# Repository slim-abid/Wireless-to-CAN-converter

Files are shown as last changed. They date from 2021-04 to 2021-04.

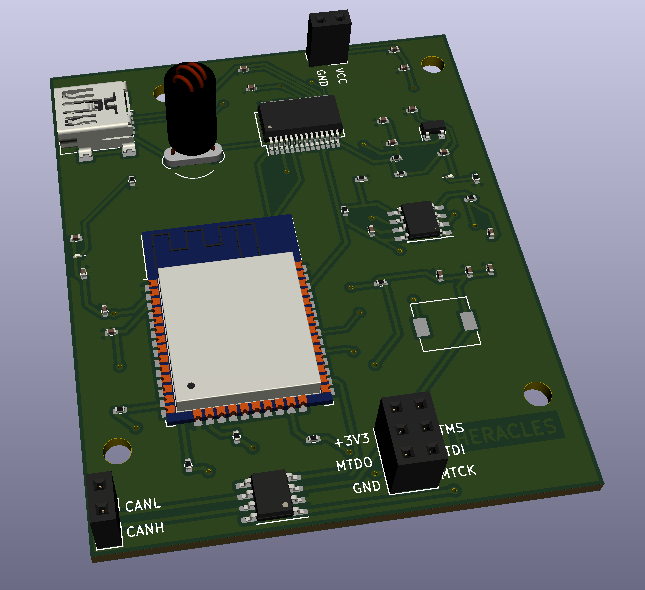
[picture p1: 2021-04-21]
Assets/heracles 3D view.png

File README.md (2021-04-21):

# **Wireless to CAN converter**

Heracles is a qualified board for Automotive Applications.
The board was designed by KiCad.
It introduces the convertion between wireless connection (Bluetooth,BLE,WIFI) and CAN with the following features:

 - [ ] introduces a jtag debugging interface.
 
 - [ ] can be configured and managed by the integrated USB interface.
 
 - [ ] uses 3.8 to 38 V dc alimentation with very low drop down voltage
       values and very low power consumption .
 - [ ] ESP32­WROOM­32 running at 40Mhz to 160MHz.
 
 - [ ] A USB to UART converter.
 
 - [ ] USB type B port.
 
 - [ ] low-power co-processor that can be used instead of the CPU to
       save power while performing tasks that do not require much
       computing power, such as monitoring of peripherals.
       
 - [ ] Wireless connectivity: WI-FI (802.11 b/g/n ,802.11n up to 150
       Mbps), Bluetooth v4.2 and BLE.

## Schematic:



## PCB Routing
heracles2
*All this capabilities are just in 6.65cmx5.35cm board.*

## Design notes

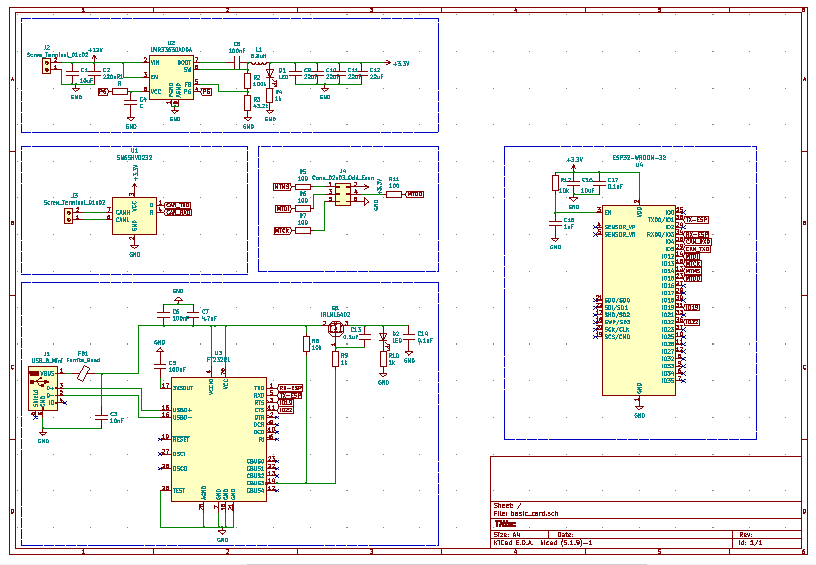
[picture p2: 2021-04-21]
Assets/HeraclesSchema.png

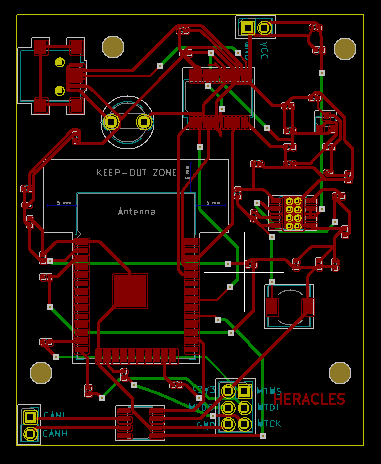
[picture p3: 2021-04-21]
Assets/heracles PCB routing.png

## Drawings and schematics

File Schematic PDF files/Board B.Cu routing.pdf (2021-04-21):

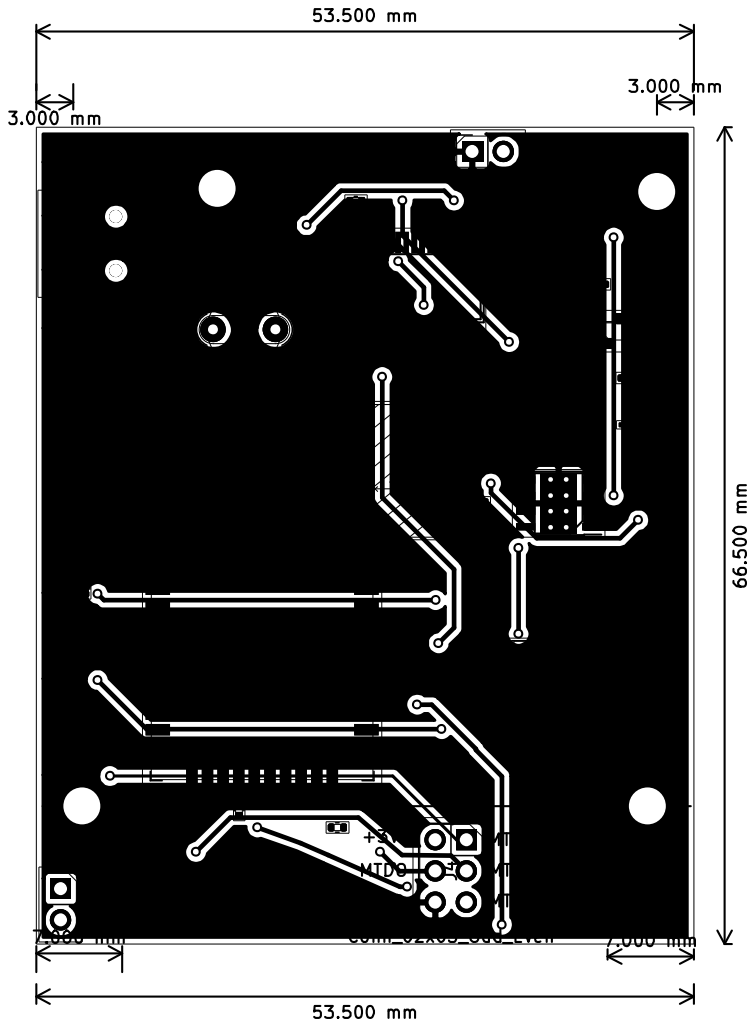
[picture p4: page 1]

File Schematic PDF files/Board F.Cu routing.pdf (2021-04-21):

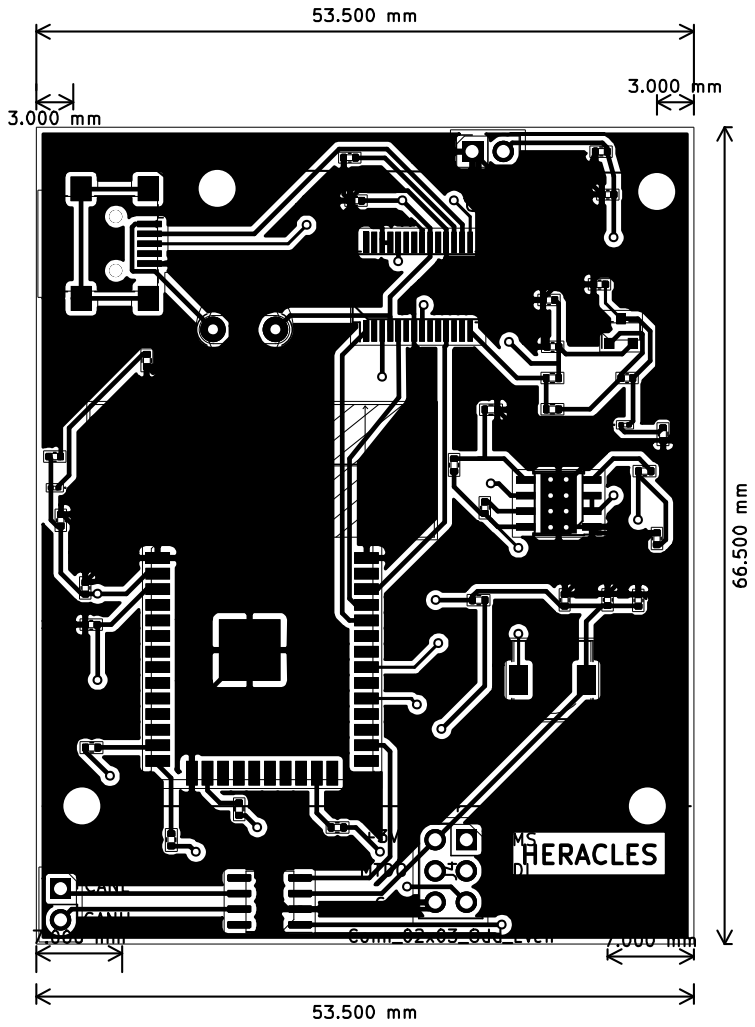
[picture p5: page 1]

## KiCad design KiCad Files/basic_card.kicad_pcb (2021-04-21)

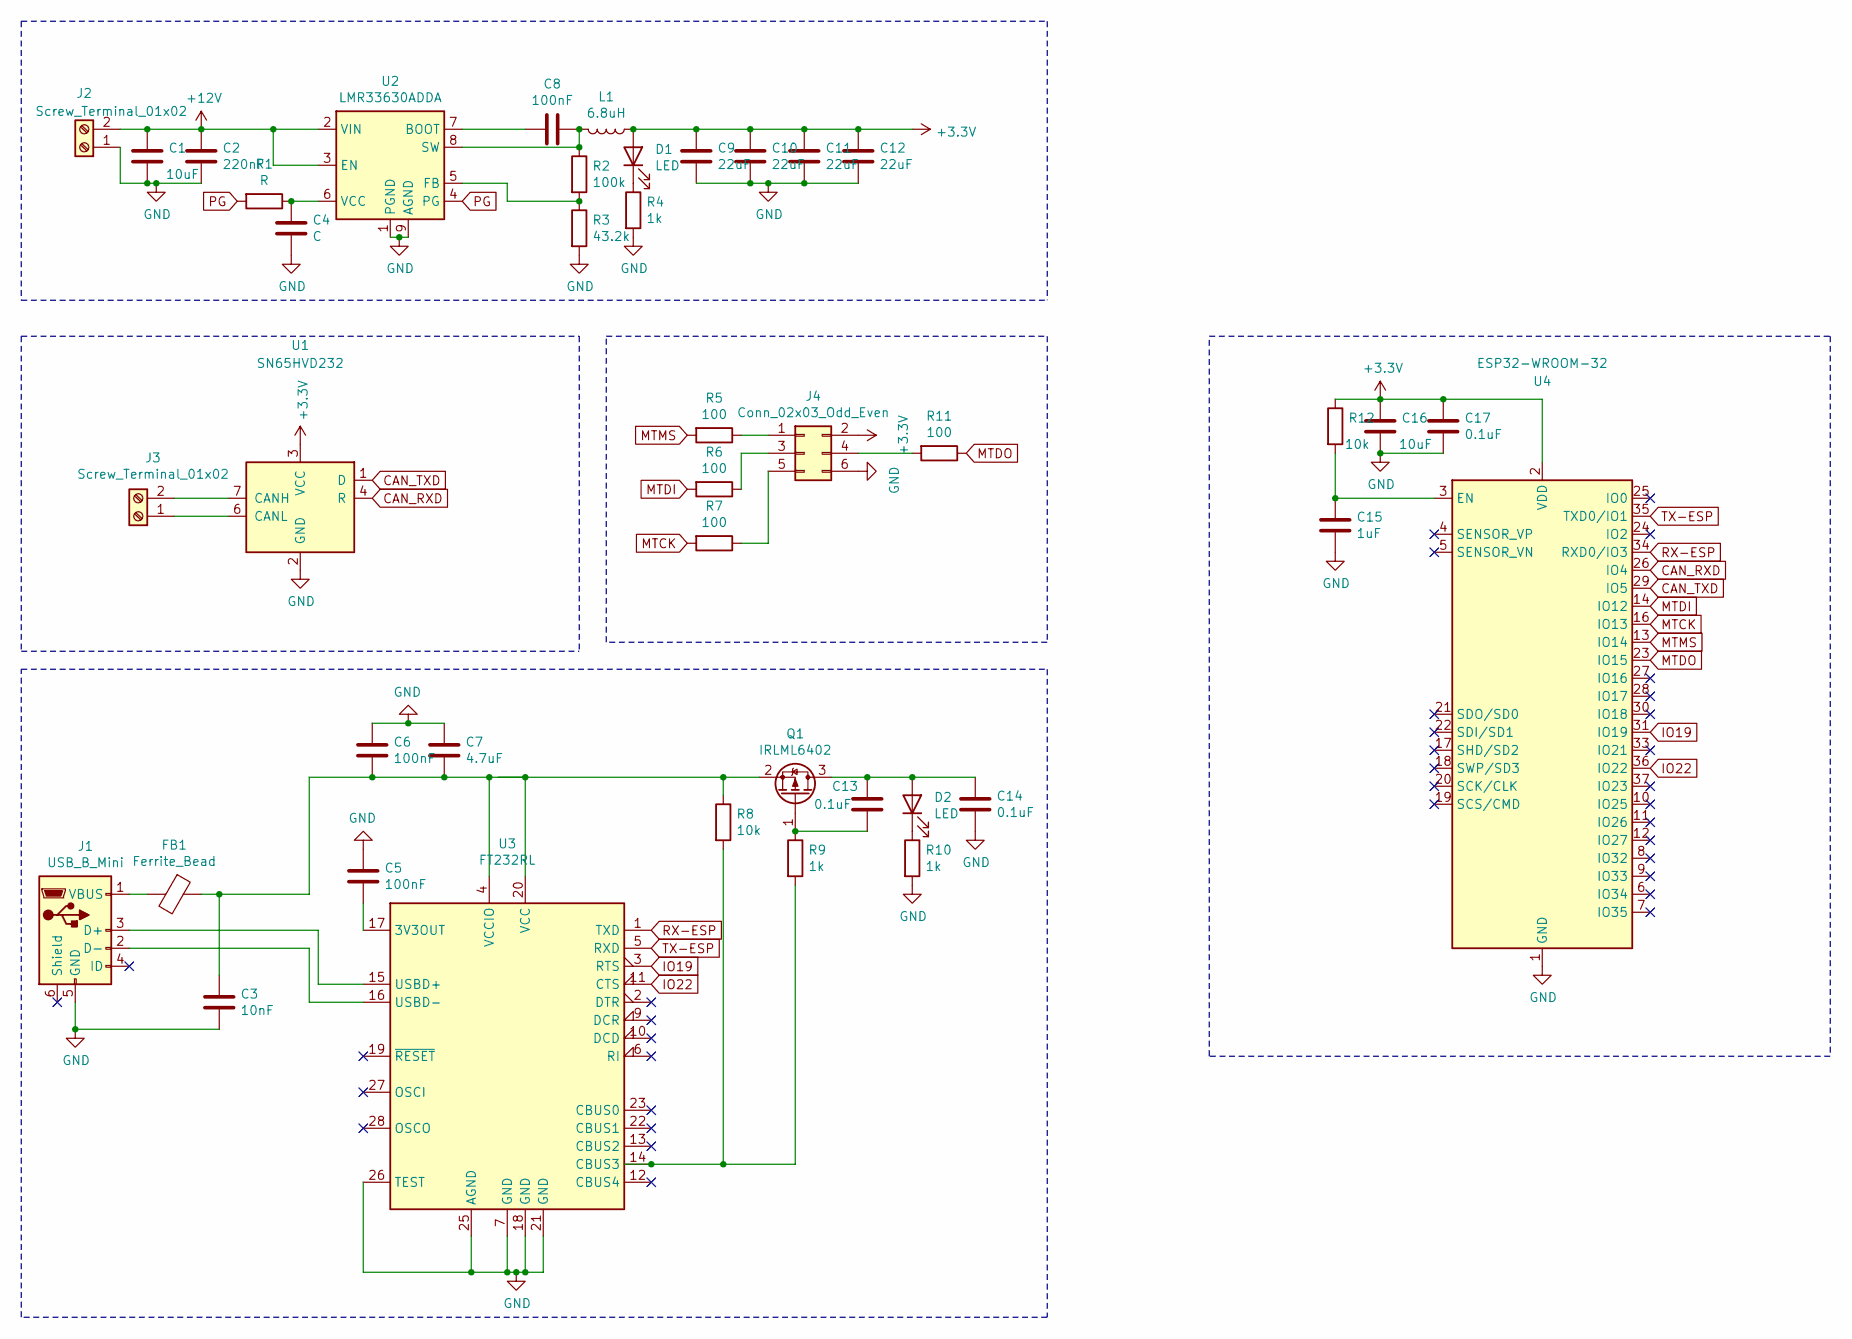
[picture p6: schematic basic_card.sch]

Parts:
C1, C16: 10uF; C_0402_1005Metric
C2: 220nF; C_0402_1005Metric
C3: 10nF; C_0402_1005Metric
C4: C; C_0402_1005Metric
C5, C6, C8: 100nF; C_0402_1005Metric
C7: 4.7uF; C_0402_1005Metric
C9, C10, C11, C12: 22uF; C_0402_1005Metric
C13, C14, C17: 0.1uF; C_0402_1005Metric
C15: 1uF; C_0402_1005Metric
D1, D2: LED; LED_0201_0603Metric
FB1: Ferrite_Bead; LairdTech_28C0236-0JW-10
J1: USB_B_Mini; USB_Mini-B_Lumberg_2486_01_Horizontal
J2, J3: Screw_Terminal_01x02; PinSocket_1x02_P2.54mm_Vertical
J4: Conn_02x03_Odd_Even; PinSocket_2x03_P2.54mm_Vertical
L1: 6.8uH; L_6.3x6.3_H3
Q1: IRLML6402; SOT-23
R1: R; R_0402_1005Metric
R2: 100k; R_0402_1005Metric
R3: 43.2k; R_0402_1005Metric
R4, R9, R10: 1k; R_0402_1005Metric
R5, R6, R7, R11: 100; R_0402_1005Metric
R8, R12: 10k; R_0402_1005Metric
U1: SN65HVD232; SOIC-8_3.9x4.9mm_P1.27mm
U2: LMR33630ADDA; Texas_HSOP-8-1EP_3.9x4.9mm_P1.27mm_ThermalVias
U3: FT232RL; SSOP-28_5.3x10.2mm_P0.65mm
U4: ESP32-WROOM-32

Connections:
+3V3: C9.1, C10.1, C11.1, C12.1, C16.1, C17.1, D1.2 (A), J4.2, L1.1, R12.1, U1.3 (VCC), U4.2 (VDD)
+12V: C1.1, C2.1, J2.2, U2.2 (VIN), U2.3 (EN)
CAN_RXD: U1.4 (R), U4.26 (IO4)
CAN_TXD: U1.1 (D), U4.29 (IO5)
GND: C1.2, C2.2, C3.2, C4.2, C5.1, C6.1, C7.1, C9.2, C10.2, C11.2, C12.2, C14.2, C15.2, C16.2, C17.2, J1.5 (GND), J2.1, J4.6, R3.2, R4.2, R10.2, U1.2 (GND), U2.1 (PGND), U2.9 (AGND), U3.7 (GND), U3.18 (GND), U3.21 (GND), U3.25 (AGND), U3.26 (TEST), U4.1 (GND), U4.15 (GND), U4.38 (GND), U4.39 (GND)
IO19: U3.3 (RTS), U4.31 (IO19)
IO22: U3.11 (CTS), U4.36 (IO22)
MTCK: R7.2, U4.16 (IO13)
MTDI: R6.2, U4.14 (IO12)
MTDO: R11.1, U4.23 (IO15)
MTMS: R5.2, U4.13 (IO14)
unnamed: C3.1, C6.2, C7.2, FB1.1, Q1.2 (S), R8.1, U3.4 (VCCIO), U3.20 (VCC)
unnamed: C4.1, R1.1, U2.6 (VCC)
unnamed: C5.2, U3.17 (3V3OUT)
unnamed: C8.1, L1.2, R2.1, U2.8 (SW)
unnamed: C8.2, U2.7 (BOOT)
unnamed: C13.1, C14.1, D2.2 (A), Q1.3 (D)
unnamed: C13.2, Q1.1 (G), R9.1
unnamed: C15.1, R12.2, U4.3 (EN)
unnamed: D1.1 (K), R4.1
unnamed: D2.1 (K), R10.1
unnamed: FB1.2, J1.1 (VBUS)
unnamed: J1.2 (D-), U3.16 (USBD-)
unnamed: J1.3 (D+), U3.15 (USBD+)
unnamed: J3.1, U1.6 (CANL)
unnamed: J3.2, U1.7 (CANH)
unnamed: J4.1, R5.1
unnamed: J4.3, R6.1
unnamed: J4.4, R11.2
unnamed: J4.5, R7.1
unnamed: R2.2, R3.1, U2.5 (FB)
unnamed: R8.2, R9.2, U3.14 (CBUS3)
PG: R1.2, U2.4 (PG)
RX-ESP: U3.1 (TXD), U4.34 (RXD0/IO3)
TX-ESP: U3.5 (RXD), U4.35 (TXD0/IO1)

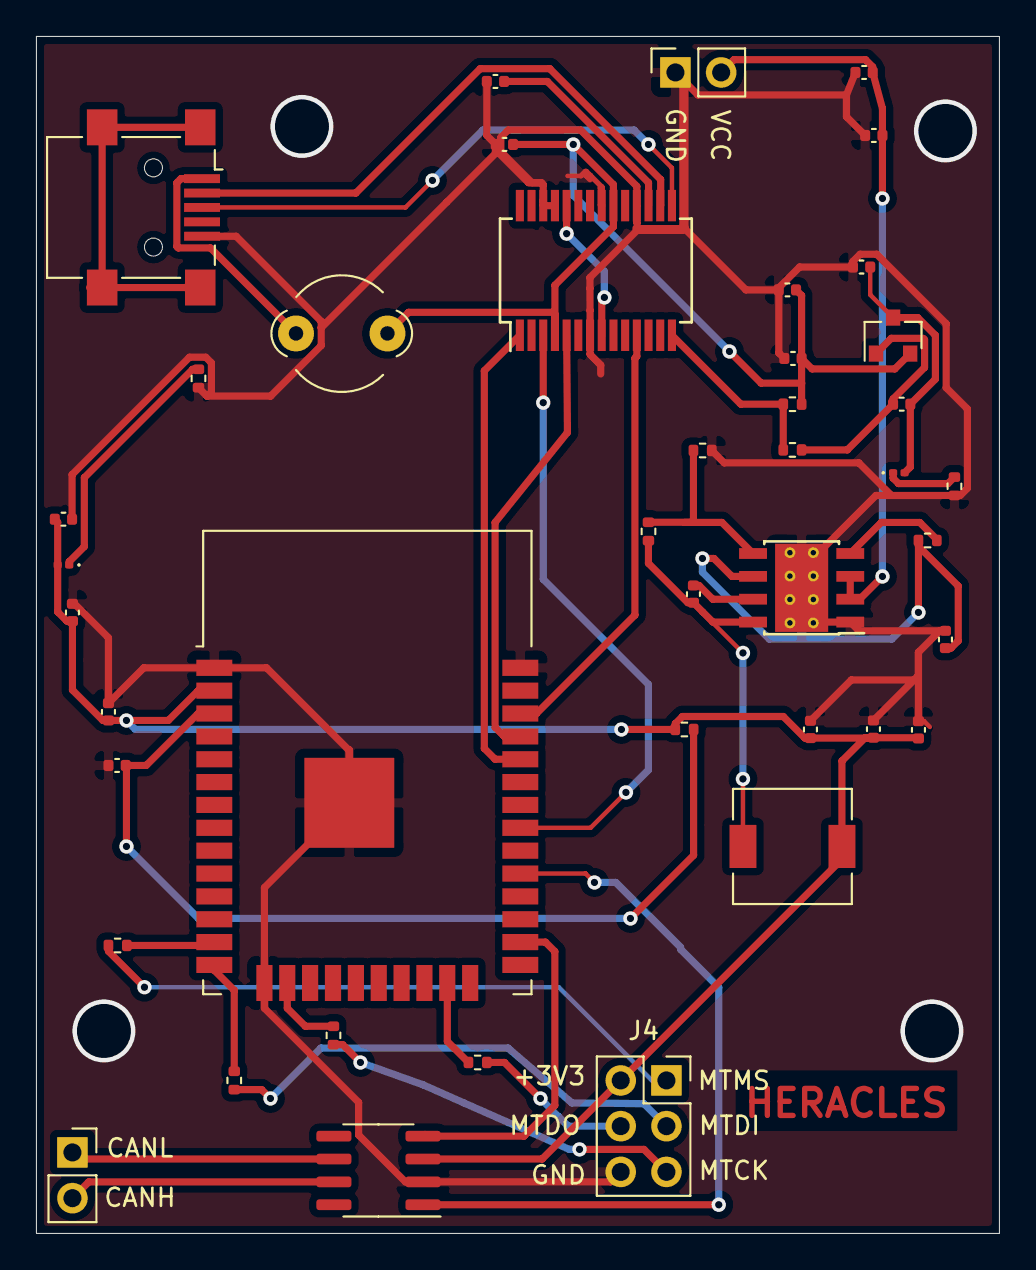
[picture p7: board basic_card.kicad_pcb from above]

Board: 2 copper layers, 53.5 x 66.5 mm, 42 parts (0 on the bottom side), 35 nets.
